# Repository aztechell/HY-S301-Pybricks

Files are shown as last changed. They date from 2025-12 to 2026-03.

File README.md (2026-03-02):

# HY-S301 Line Sensor для Pybricks (SPIKE Prime)

Этот проект позволяет использовать **8-канальный линейный датчик HY-S301 / HW-529** в качестве полноценного LPF2‑сенсора для LEGO SPIKE Prime с прошивкой **Pybricks**.

Arduino Pro Micro эмулирует LPF2‑устройство и передаёт данные по UART. Датчик работает как `PUPDevice`.

---

# Hardware

## Компоненты
- Датчик линии 8 канальный HY-S301 
- Модуль HW-529 аналогового 8-и канального мультиплексора
- Arduino Pro Micro
- 2× винта M3 + гайки
- распечатанное крепление [HY-S301_Lego_mount.stl](HY-S301_Lego_mount.stl)
- Провод LPF2

## Изображения

| | |
|---|---|
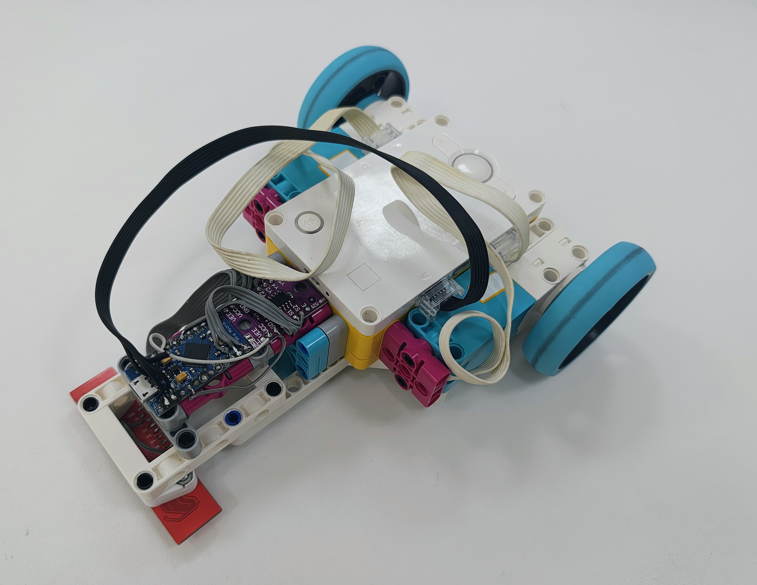
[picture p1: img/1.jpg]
|  |  |
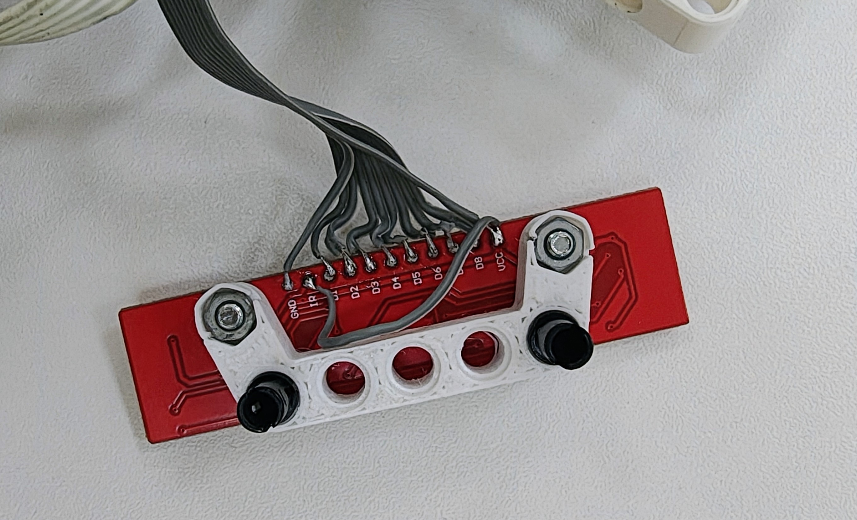
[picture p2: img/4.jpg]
|  |  |

## Робот
[line_follower_base.io](line_follower_base.io) — модель SPIKE-робота для демонстрациии движения по линии.

---

## Проводка

### 🎛 Arduino Pro Micro → HW-529 → HY‑S301

```
HW-529       Pro Micro
------------------------
S0        →   D7 
S1        →   D8
S2        →   D9
OUT       →   A1
VCC       →   5V
GND       →   GND
```

```
HW-529        HY‑S301       
------------------------
VCC       →   VCC
VCC       →   IR
GND       →   GND
Y0        →   D8
Y1        →   D7
Y2        →   D6
Y3        →   D5
Y4        →   D4
Y5        →   D3
Y6        →   D2
Y7        →   D1

```

### 🔌 Arduino Pro Micro → SPIKE Prime (LPF2 UART)

```
SPIKE Prime       Pro Micro
----------------------------
RX (6)           →    TX0 (D1)
TX (5)           →    RX1 (D0)
3.3V (4)         →    VCC
GND (3)          →    GND
```
[Spike Prime wiring](https://github.com/GianCann/SpikePrimeHub/blob/master/LEGO%20Spike%20Prime%20pin%20map.png).

---

# Software

## Зависимость (Arduino)
Используется библиотека:

**LumpDeviceBuilder**  
https://github.com/devilhyt/lump-device-builder-library

---

## Первая версия (совместимая с MBC‑датчиком)

Файлы лежат в папке mbc_compatible.

Эмуляция датчика:

**MBC Line Following Sensor**  
https://www.axione.shop/product-page/mbc-line-following-sensor

Выдаёт те же данные, что и оригинал.

---

## Вторая версия (простая LINE8)

Прошивка Arduino в папке *code*.

Передаёт ровно **8 байт (0–255)** — значения каналов слева направо.

Пример чтения в pybricks [sensor_read.py](sensor_read.py)

Также есть простой пример движения по линии. [LineFollower_simple.py](LineFollower_simple.py)

---

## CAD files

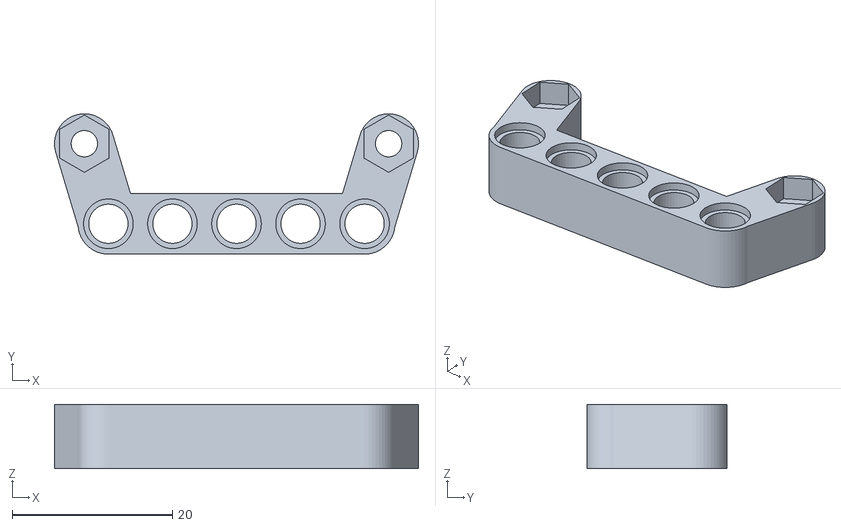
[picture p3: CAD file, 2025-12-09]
HY-S301_Lego_mount.stl
45.5 x 17.5 x 8.00

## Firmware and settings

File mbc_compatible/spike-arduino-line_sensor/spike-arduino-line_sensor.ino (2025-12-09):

#define LUMP_HOST_DETECT_OFF

#include <LumpDeviceBuilder.h>

// --------------------------------------------------
// LPF2 (PUP) UART over Serial1 (Pro Micro / 32U4)
// --------------------------------------------------
#define DEVICE_SERIAL Serial1
#define RX_PIN 0  // D0 / RX1
#define TX_PIN 1  // D1 / TX0
#define BAUDRATE 115200

// --------------------------------------------------
// Линия датчиков HW-529 / HY-S301
// --------------------------------------------------
#define S0_PIN 7
#define S1_PIN 8
#define S2_PIN 9
#define LINE_ANALOG A1  // аналоговый выход мультиплексора

// --------------------------------------------------
// Описание режимов как у SPIKE Color Sensor
// --------------------------------------------------
LumpMode modes[] = {
  // 0: COLOR (DATA8,1)
  { "COLOR", DATA8, 1, 3, 0, "", { 0, 10 }, { 0, 100 }, { 0, 10 } },

  // 1: REFLT (DATA8,1)
  { "REFLT", DATA8, 1, 3, 0, "%", { 0, 100 }, { 0, 100 }, { 0, 100 } },

  // 2: AMBI (DATA8,1)
  { "AMBI", DATA8, 1, 3, 0, "%", { 0, 100 }, { 0, 100 }, { 0, 100 } },

  // 3: LIGHT (DATA8,3)
  { "LIGHT", DATA8, 3, 3, 0, "", { 0, 100 }, { 0, 100 }, { 0, 100 } },

  // 4: RREFL (DATA16,2)
  { "RREFL", DATA16, 2, 5, 0, "", { 0, 1023 }, { 0, 100 }, { 0, 1023 } },

  // 5: RGB I (DATA16,4)
  { "RGB I", DATA16, 4, 5, 0, "", { 0, 1023 }, { 0, 100 }, { 0, 1023 } },

  // 6: HSVl (DATA16,3)
  { "HSVl", DATA16, 3, 5, 0, "", { 0, 1023 }, { 0, 100 }, { 0, 1023 } },

  // 7: SHSV (DATA16,4)
  { "SHSV", DATA16, 4, 5, 0, "", { 0, 1023 }, { 0, 100 }, { 0, 1023 } },

  // 8: DEBUG (DATA16,4)
  { "DEBUG", DATA16, 4, 5, 0, "", { 0, 65535 }, { 0, 100 }, { 0, 65535 } },

  // 9: CALIB (DATA16,7) — line-sensor пакет
  { "CALIB", DATA16, 7, 5, 0, "", { 0, 65535 }, { 0, 100 }, { 0, 65535 } },
};

uint8_t numModes = sizeof(modes) / sizeof(LumpMode);

// type = 61 → SPIKE_COLOR_SENSOR
LumpDevice<HardwareSerial> device(
  &DEVICE_SERIAL,
  RX_PIN,
  TX_PIN,
  61,
  BAUDRATE,
  modes,
  numModes);

// --------------------------------------------------
// Состояние линии
// --------------------------------------------------
struct LineState {
  uint8_t vals[8];  // 0..255
  uint8_t threshold;
  uint8_t blackBin;
  uint8_t whiteBin;
  uint8_t blackWidth;
  uint8_t whiteWidth;
  int8_t blackErr;   // -7..+7
  int8_t whiteErr;   // -7..+7
  int16_t calib[7];  // пакет для CALIB (mode 9)
} ls;


// --------------------------------------------------
// Утилиты
// --------------------------------------------------
inline void selectChannel(uint8_t ch) {
  digitalWrite(S0_PIN, (ch >> 0) & 1);
  digitalWrite(S1_PIN, (ch >> 1) & 1);
  digitalWrite(S2_PIN, (ch >> 2) & 1);
}

inline uint8_t analogToByte(int raw) {
  if (raw < 0) raw = 0;
  if (raw > 1023) raw = 1023;
  return (uint8_t)((uint32_t)raw * 255UL / 1023UL);
}

inline uint8_t popcount8(uint8_t x) {
  uint8_t c = 0;
  while (x) {
    x &= (x - 1);
    c++;
  }
  return c;
}

int8_t calcError(uint8_t mask) {
  const int8_t w[8] = { -7, -5, -3, -1, 1, 3, 5, 7 };
  int16_t sum = 0, cnt = 0;
  for (uint8_t i = 0; i < 8; i++) {
    if (mask & (1 << i)) {
      sum += w[i];
      cnt++;
    }
  }
  return (cnt == 0) ? 0 : (int8_t)(sum / cnt);
}

// --------------------------------------------------
// Обновление линии + заполнение CALIB
// --------------------------------------------------

void updateLineState() {
  uint8_t minv = 255;
  uint8_t maxv = 0;

  for (uint8_t i = 0; i < 8; i++) {
    // читаем физический канал 7,6,5,4,3,2,1,0
    uint8_t ch = 7 - i;
    selectChannel(ch);
    delayMicroseconds(5);
    uint8_t v = analogToByte(analogRead(LINE_ANALOG));

    // а в массив кладём уже в "логическом" порядке:
    // ls.vals[0] = левый, ls.vals[7] = правый
    ls.vals[i] = v;

    if (v < minv) minv = v;
    if (v > maxv) maxv = v;
  }

  ls.threshold = (uint8_t)((minv + maxv) / 2);

  ls.blackBin = 0;
  ls.whiteBin = 0;

  for (uint8_t i = 0; i < 8; i++) {
    if (ls.vals[i] < ls.threshold)
      ls.blackBin |= (1 << i);
    else
      ls.whiteBin |= (1 << i);
  }

  ls.blackWidth = popcount8(ls.blackBin);
  ls.whiteWidth = popcount8(ls.whiteBin);

  ls.blackErr = calcError(ls.blackBin);
  ls.whiteErr = calcError(ls.whiteBin);

  uint8_t blackErrEnc = (uint8_t)(ls.blackErr + 8);
  uint8_t whiteErrEnc = (uint8_t)(ls.whiteErr + 8);

  // CALIB-пакет (mode 9) остаётся тем же — но теперь vals уже в нужном порядке
  ls.calib[0] = ((int16_t)ls.vals[1] << 8) | ls.vals[0];
  ls.calib[1] = ((int16_t)ls.vals[3] << 8) | ls.vals[2];
  ls.calib[2] = ((int16_t)ls.vals[5] << 8) | ls.vals[4];
  ls.calib[3] = ((int16_t)ls.vals[7] << 8) | ls.vals[6];
  ls.calib[4] = ((int16_t)ls.blackWidth << 8) | blackErrEnc;
  ls.calib[5] = ((int16_t)whiteErrEnc << 8) | ls.blackBin;
  ls.calib[6] = ((int16_t)ls.whiteBin << 8) | ls.whiteWidth;
}



// --------------------------------------------------
// Отправка данных в зависимости от режима
// --------------------------------------------------
void sendModeData(uint8_t mode) {

  // Mode 0: (0,)
  if (mode == 0) {
    uint8_t v = 0;
    device.send(v);  // DATA8,1
    return;
  }

  // Mode 1: (8,)
  if (mode == 1) {
    uint8_t v = 8;
    device.send(v);
    return;
  }

  // Mode 2: (8,)
  if (mode == 2) {
    uint8_t v = 8;
    device.send(v);
    return;
  }

  // Mode 3: (8, 0, 0)
  if (mode == 3) {
    uint8_t arr[3] = { 8, 0, 0 };
    device.send(arr, 3);  // DATA8,3
    return;
  }

  // Mode 4: (2048, 2048)
  if (mode == 4) {
    int16_t arr[2] = { 2048, 2048 };
    device.send(arr, 2);  // DATA16,2
    return;
  }

  // Mode 5: (827, 827, 827, 0)
  if (mode == 5) {
    int16_t arr[4] = { 827, 827, 827, 0 };
    device.send(arr, 4);  // DATA16,4
    return;
  }

  // Mode 6: (25700, 25700, 25700)
  if (mode == 6) {
    int16_t arr[3] = { 25700, 25700, 25700 };
    device.send(arr, 3);  // DATA16,3
    return;
  }

  // Mode 7: (8, 2056, 880, 800)
  if (mode == 7) {
    int16_t arr[4] = { 8, 2056, 880, 800 };
    device.send(arr, 4);  // DATA16,4
    return;
  }

  // Mode 8: (25700, 25700, 880, 800)
  if (mode == 8) {
    int16_t arr[4] = { 25700, 25700, 880, 800 };
    device.send(arr, 4);  // DATA16,4
    return;
  }

  // Mode 9: CALIB — реальный line-sensor пакет
  if (mode == 9) {
    device.send(ls.calib, 7);  // DATA16,7
    return;
  }
}


// --------------------------------------------------
// LUMP state machine c таймером
// --------------------------------------------------
void runDeviceModes() {
  uint32_t now = millis();
  static uint32_t prev = 0;

  // Обновляем сенсоры и отправляем данные раз в ~10 мс
  if (now - prev >= 10) {
    prev = now;

    updateLineState();

    if (device.state() == LumpDeviceState::Communicating) {
      sendModeData(device.mode());
    }
  }
}


// --------------------------------------------------
// setup / loop
// --------------------------------------------------
void setup() {
  DEVICE_SERIAL.begin(BAUDRATE);
  device.begin();

  pinMode(S0_PIN, OUTPUT);
  pinMode(S1_PIN, OUTPUT);
  pinMode(S2_PIN, OUTPUT);
  pinMode(LINE_ANALOG, INPUT);
}

void loop() {
  device.run();      // протокол LPF2
  runDeviceModes();  // логика режимов + линия по таймеру
}

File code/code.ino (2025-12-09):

#define LUMP_HOST_DETECT_OFF

#include <LumpDeviceBuilder.h>

// --------------------------
// LPF2 (PUP) over Serial1
// --------------------------
#define DEVICE_SERIAL Serial1
#define RX_PIN        0      // D0 / RX1
#define TX_PIN        1      // D1 / TX0
#define BAUDRATE      115200

// --------------------------
// Линейный датчик (мультиплексор)
// --------------------------
#define S0_PIN        7
#define S1_PIN        8
#define S2_PIN        9
#define LINE_ANALOG   A1     // аналоговый выход мультиплексора

// --------------------------
// Один простой режим: 8 байт
// --------------------------
// name="LINE8", type=DATA8, numData=8
LumpMode modes[] = {
  { "LINE8", DATA8, 8, 3, 0, "",
    {0, 255}, {0, 100}, {0, 255} }
};

uint8_t numModes = sizeof(modes) / sizeof(LumpMode);

// type = 61 (можно оставить как у color sensor)
LumpDevice<HardwareSerial> device(
  &DEVICE_SERIAL,
  RX_PIN,
  TX_PIN,
  61,
  BAUDRATE,
  modes,
  numModes
);


// --------------------------
// Утилиты
// --------------------------
inline void selectChannel(uint8_t ch) {
  digitalWrite(S0_PIN, (ch >> 0) & 1);
  digitalWrite(S1_PIN, (ch >> 1) & 1);
  digitalWrite(S2_PIN, (ch >> 2) & 1);
}

inline uint8_t analogToByte(int raw) {
  if (raw < 0)   raw = 0;
  if (raw > 1023) raw = 1023;
  return (uint8_t)((uint32_t)raw * 255UL / 1023UL);
}


// --------------------------
// Чтение 8 каналов (левый→правый)
// --------------------------
void readLine(uint8_t out[8]) {
  for (uint8_t i = 0; i < 8; i++) {
    // физически читаем каналы 7,6,5,4,3,2,1,0
    uint8_t ch = 7 - i;
    selectChannel(ch);
    delayMicroseconds(5);
    int raw = analogRead(LINE_ANALOG);

    // логически складываем как [0..7] = слева направо
    out[i] = analogToByte(raw);
  }
}


// --------------------------
// LUMP state machine
// --------------------------
void runDeviceModes() {
  static uint32_t prev = 0;
  uint32_t now = millis();

  // Обновление и отправка раз в ~10 мс
  if (now - prev >= 10) {
    prev = now;

    if (device.state() == LumpDeviceState::Communicating) {
      uint8_t line[8];
      readLine(line);      // просто 8 байт 0..255
      device.send(line, 8);
    }
  }
}


// --------------------------
// setup / loop
// --------------------------
void setup() {
  DEVICE_SERIAL.begin(BAUDRATE);
  device.begin();

  pinMode(S0_PIN, OUTPUT);
  pinMode(S1_PIN, OUTPUT);
  pinMode(S2_PIN, OUTPUT);
  pinMode(LINE_ANALOG, INPUT);
}

void loop() {
  device.run();
  runDeviceModes();
}

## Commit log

2025-12-22 Revise wiring details for Arduino Pro Micro and HY-S301
    Updated wiring instructions for Arduino Pro Micro and HY-S301.
2026-03-02 Fix wiring table formatting in README.md
